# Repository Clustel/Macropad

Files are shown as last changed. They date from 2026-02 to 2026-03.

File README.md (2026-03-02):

# Squish Pad
A fully 3D-printable, true gasket-mounted 4x4 macropad engineered for a premium, ultra-smooth typing experience.

# Features
	16-Key Matrix + Rotary Encoder
	Engineered Leaf-Spring Plate providing a bouncy, trampoline-like typing fee
	Utilizes 3D-printed "slip-on" gasket socks to sandwich the plate tabs, completely isolating the plate and PCB from the outer case.
	Acoustic PCB Cushion

# Rendering


# Schematic
hackpad schematic

# PCB
hackpad pcb

# BOM
	1x unsoldered Seeed XIAO RP2040
	16x through-hole 1N4148 Diodes
	15x MX-Style switches
	1x EC11 Rotary encoders
	15x white blank DSA keycaps
	16x SK6812 MINI-E LEDs
	4x M3x16mm screws
	4x M3x5mx4mm heatset inserts
	1x Printed PCB
	1x Case (All parts, guide below)

# Printing Guide

> **If you dont have TPU:** Print the gaskets with PLA/PETG and don't print the cushion. The macropad will still be slightly flexible

| Part | Material | Key Settings |
| :--- | :--- | :--- |
| **Top & Bottom Case** | PLA-CF / PLA | Wall Loops: **5** \| Infill: **25% Gyroid** \| Layer: **0.16mm** |
| **Leaf-Spring Plate** | PETG | Wall Loops: **4** \| Layer: **0.15mm** \| Top/Bottom Layers: **5** |
| **Gaskets (x4)** | 95A TPU | Walls: **2** \| Top/Bottom: **0** \| Infill: **12% Gyroid** \| Speed: **3.5mm³/s** |
| **Cushion** | 95A TPU | Walls: **1** \| Top/Bottom: **0** \| Infill: **6% Gyroid** \| Speed: **3.5mm³/s** |

> **Note:** For the TPU parts, setting Top and Bottom layers to **0** is critical, this exposes the Gyroid infill to create the "squish" effect.

# Assembly guide
_Ensure all 3D-printed parts are cleaned of support material before starting._

> Bottom Case
> 
> 

> Add Cushion (if using TPU)
> 
> 

> Assemble PCB (might be easier to add keycaps in the next step)
> 
> 

> Add Plate
> 
> 

> Put assembly on top of cushion
>
> 

> Put Gaskets on all four sides of plate
> 
> 

> Add top (put heat inserts in the 4 holes)
> 
> 

> Use the screws to attach it together
> 
> 

> Done!
> 
>

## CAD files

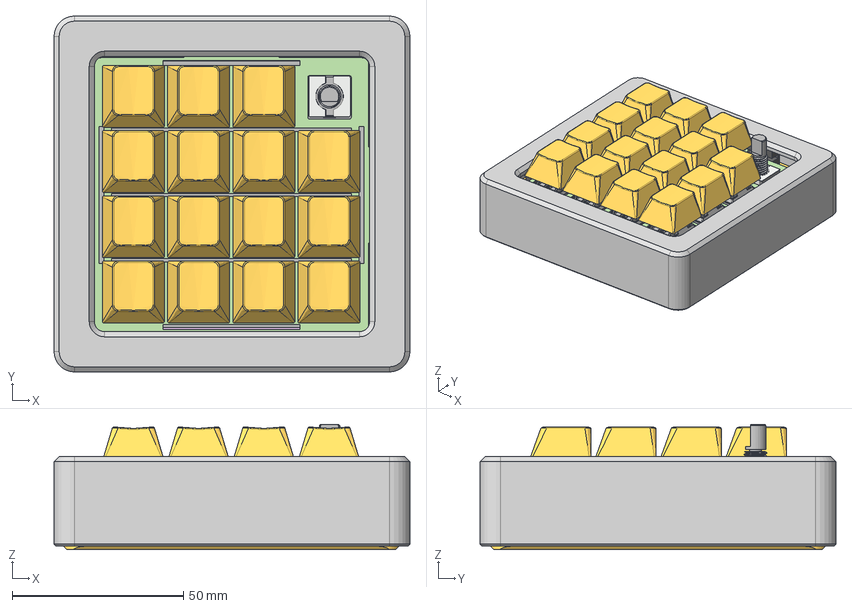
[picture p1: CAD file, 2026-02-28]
CAD/CAD Assembly.step
104.0 x 104.0 x 36.6 mm
Base
Socket button head screw M3x0.5 x 16 x 4
Gasket x 4
Top
r1_100 x 15
��ת������ x 6
Smaller pad
MX ? ??��_�?�__ x 15
MX? ?? ?? ?�2__??_�2____�_ x 15
MX ? ???_�___�1 x 15
??___??__�_ x 30
Seeed Studio XIAO RP2040 v26 x 36
type-c v2 x 24
main x 16
smd_button v3(Mirror)
VSS
VDD
DIN
DOUT
smd_button v3

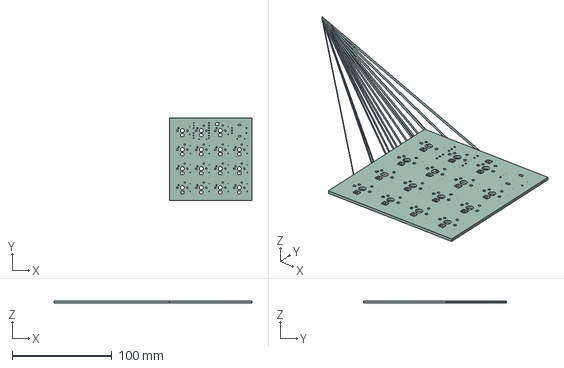
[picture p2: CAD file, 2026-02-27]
PCB/Custom Macropad.step
198.4 x 142.9 x 1.51 mm

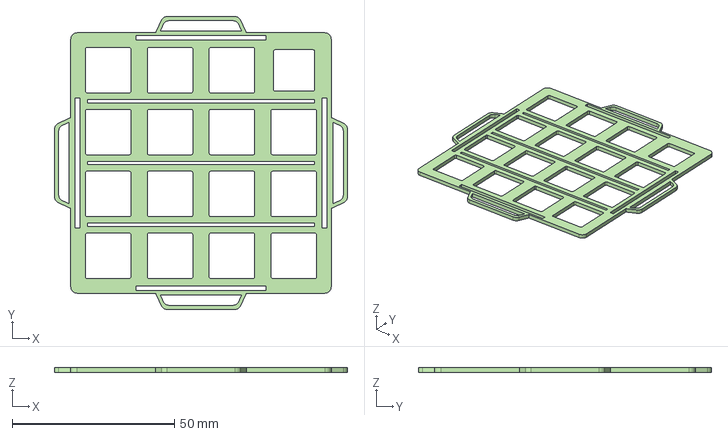
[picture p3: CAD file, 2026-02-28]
Production/Plate.step
90.2 x 90.2 x 1.51 mm

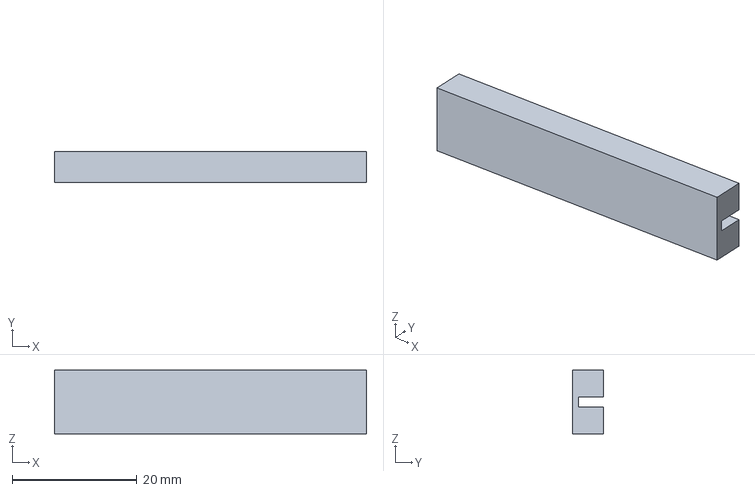
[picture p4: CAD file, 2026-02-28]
Production/Gasket x4.step
50.0 x 5.00 x 10.2 mm

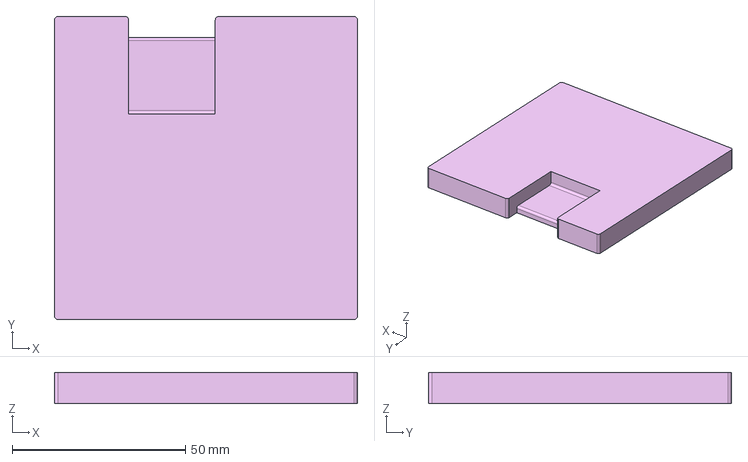
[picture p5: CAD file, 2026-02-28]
Production/Cushion.step
87.5 x 87.5 x 9.00 mm

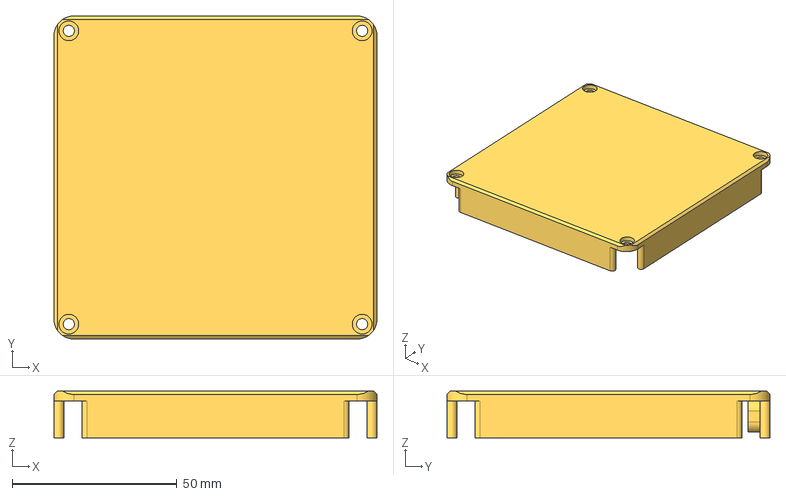
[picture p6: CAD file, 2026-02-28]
Production/Bottom.step
98.0 x 98.0 x 14.2 mm

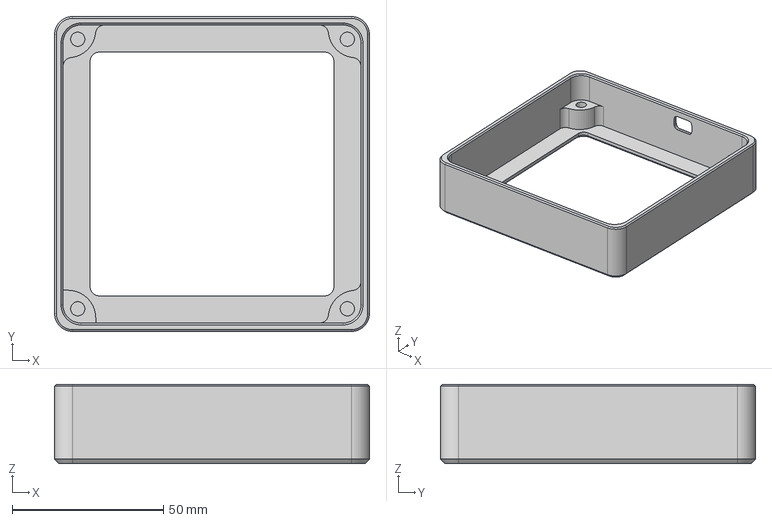
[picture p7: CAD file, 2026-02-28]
Production/Top.step
104.0 x 104.0 x 26.2 mm

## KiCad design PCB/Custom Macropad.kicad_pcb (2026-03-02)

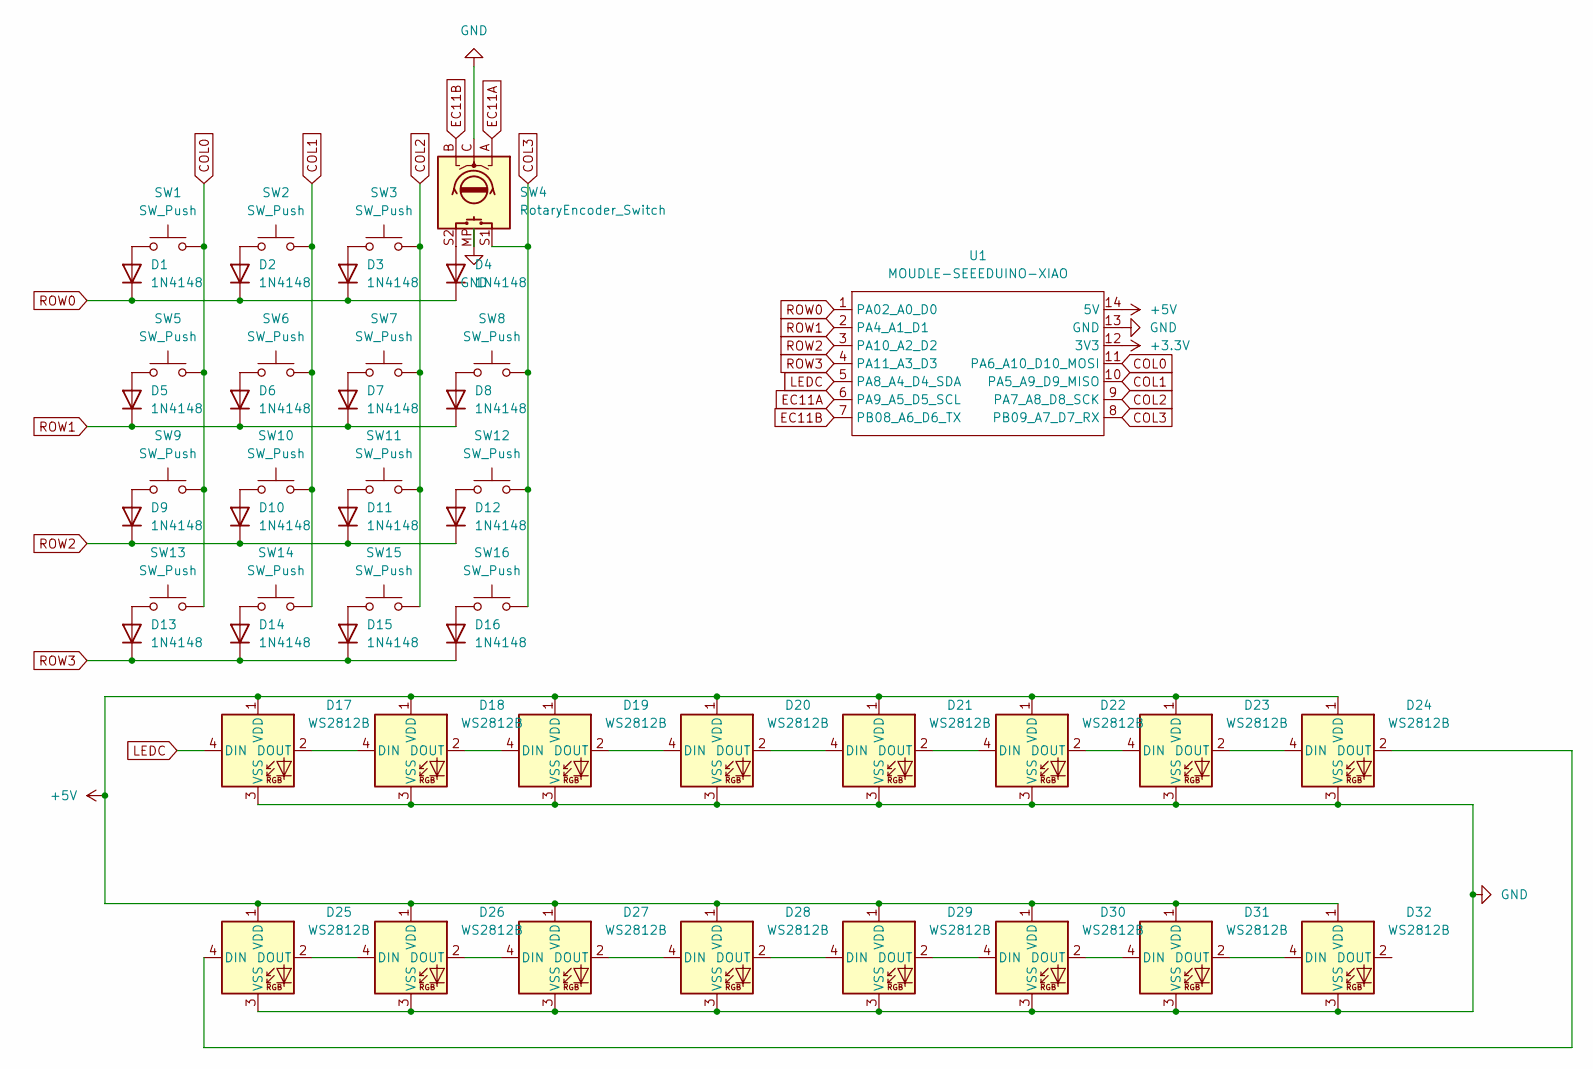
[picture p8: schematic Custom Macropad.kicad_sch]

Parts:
D1, D2, D3, D4, D5, D6, D7, D8, D9, D10, D11, D12, D13, D14, D15, D16: 1N4148; D_DO-35_SOD27_P7.62mm_Horizontal
D17, D18, D19, D20, D21, D22, D23, D24, D25, D26, D27, D28, D29, D30, D31, D32: WS2812B; SK6812MINI-E_fixed
SW1, SW2, SW3, SW5, SW6, SW7, SW8, SW9, SW10, SW11, SW12, SW13, SW14, SW15, SW16: SW_Push; SW_Cherry_MX_1.00u_PCB
SW4: RotaryEncoder_Switch; RotaryEncoder_Alps_EC11E-Switch_Vertical_H20mm
U1: MOUDLE-SEEEDUINO-XIAO; XIAO-Generic-Hybrid-14P-2.54-21X17.8MM

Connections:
+3.3V: U1.12 (3V3)
+5V: D17.1 (VDD), D18.1 (VDD), D19.1 (VDD), D20.1 (VDD), D21.1 (VDD), D22.1 (VDD), D23.1 (VDD), D24.1 (VDD), D25.1 (VDD), D26.1 (VDD), D27.1 (VDD), D28.1 (VDD), D29.1 (VDD), D30.1 (VDD), D31.1 (VDD), D32.1 (VDD), U1.14 (5V)
COL0: SW1.2, SW5.2, SW9.2, SW13.2, U1.11 (PA6_A10_D10_MOSI)
COL1: SW2.2, SW6.2, SW10.2, SW14.2, U1.10 (PA5_A9_D9_MISO)
COL2: SW3.2, SW7.2, SW11.2, SW15.2, U1.9 (PA7_A8_D8_SCK)
COL3: SW4.S1, SW8.2, SW12.2, SW16.2, U1.8 (PB09_A7_D7_RX)
EC11A: SW4.A, U1.6 (PA9_A5_D5_SCL)
EC11B: SW4.B, U1.7 (PB08_A6_D6_TX)
GND: D17.3 (VSS), D18.3 (VSS), D19.3 (VSS), D20.3 (VSS), D21.3 (VSS), D22.3 (VSS), D23.3 (VSS), D24.3 (VSS), D25.3 (VSS), D26.3 (VSS), D27.3 (VSS), D28.3 (VSS), D29.3 (VSS), D30.3 (VSS), D31.3 (VSS), D32.3 (VSS), SW4.C, SW4.MP (Shield), U1.13 (GND)
LEDC: D17.4 (DIN), U1.5 (PA8_A4_D4_SDA)
unnamed: D1.2 (A), SW1.1
unnamed: D2.2 (A), SW2.1
unnamed: D3.2 (A), SW3.1
unnamed: D4.2 (A), SW4.S2
unnamed: D5.2 (A), SW5.1
unnamed: D6.2 (A), SW6.1
unnamed: D7.2 (A), SW7.1
unnamed: D8.2 (A), SW8.1
unnamed: D9.2 (A), SW9.1
unnamed: D10.2 (A), SW10.1
unnamed: D11.2 (A), SW11.1
unnamed: D12.2 (A), SW12.1
unnamed: D13.2 (A), SW13.1
unnamed: D14.2 (A), SW14.1
unnamed: D15.2 (A), SW15.1
unnamed: D16.2 (A), SW16.1
unnamed: D17.2 (DOUT), D18.4 (DIN)
unnamed: D18.2 (DOUT), D19.4 (DIN)
unnamed: D19.2 (DOUT), D20.4 (DIN)
unnamed: D20.2 (DOUT), D21.4 (DIN)
unnamed: D21.2 (DOUT), D22.4 (DIN)
unnamed: D22.2 (DOUT), D23.4 (DIN)
unnamed: D23.2 (DOUT), D24.4 (DIN)
unnamed: D24.2 (DOUT), D25.4 (DIN)
unnamed: D25.2 (DOUT), D26.4 (DIN)
unnamed: D26.2 (DOUT), D27.4 (DIN)
unnamed: D27.2 (DOUT), D28.4 (DIN)
unnamed: D28.2 (DOUT), D29.4 (DIN)
unnamed: D29.2 (DOUT), D30.4 (DIN)
unnamed: D30.2 (DOUT), D31.4 (DIN)
unnamed: D31.2 (DOUT), D32.4 (DIN)
ROW0: D1.1 (K), D2.1 (K), D3.1 (K), D4.1 (K), U1.1 (PA02_A0_D0)
ROW1: D5.1 (K), D6.1 (K), D7.1 (K), D8.1 (K), U1.2 (PA4_A1_D1)
ROW2: D9.1 (K), D10.1 (K), D11.1 (K), D12.1 (K), U1.3 (PA10_A2_D2)
ROW3: D13.1 (K), D14.1 (K), D15.1 (K), D16.1 (K), U1.4 (PA11_A3_D3)

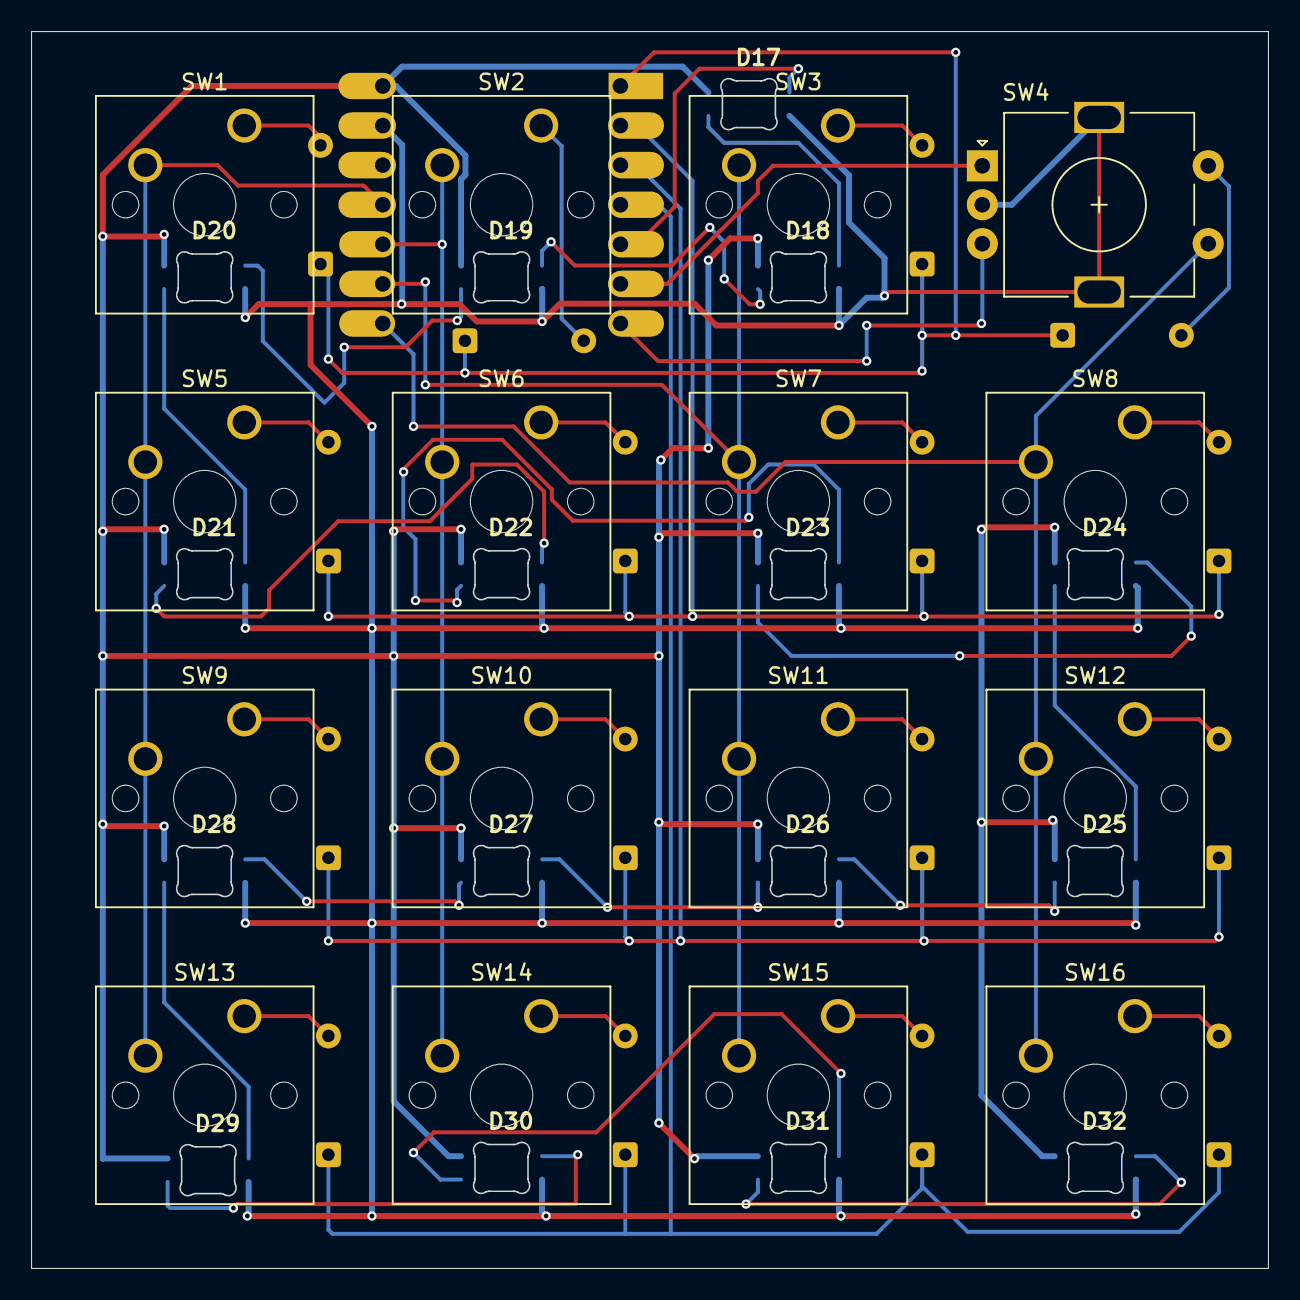
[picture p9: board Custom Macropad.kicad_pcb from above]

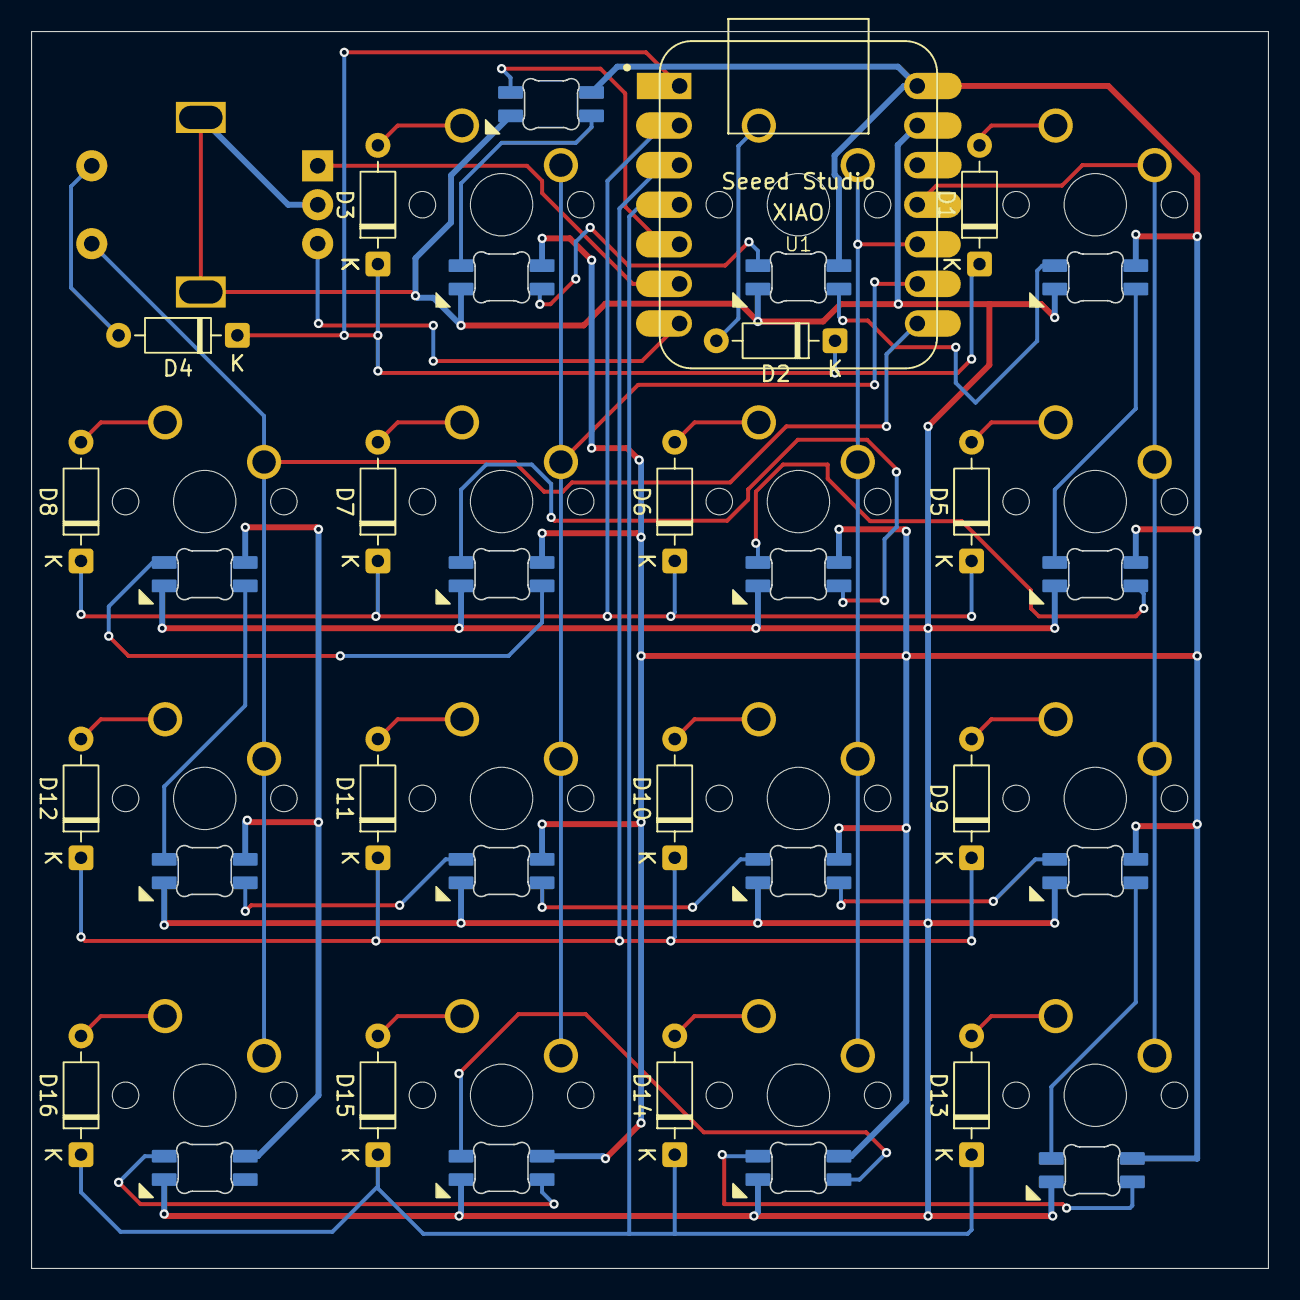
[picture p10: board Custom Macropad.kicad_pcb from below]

Board: 2 copper layers, 79.4 x 79.4 mm, 49 parts (17 on the bottom side), 44 nets.

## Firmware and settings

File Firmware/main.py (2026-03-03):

import board
from kmk.kmk_keyboard import KMKKeyboard
from kmk.keys import KC
from kmk.scanners import DiodeOrientation
from kmk.modules.encoder import EncoderHandler
from kmk.extensions.rgb import RGB

keyboard = KMKKeyboard()

keyboard.col_pins = (board.D10, board.D9, board.D8, board.D7)
keyboard.row_pins = (board.D0, board.D1, board.D2, board.D3)
keyboard.diode_orientation = DiodeOrientation.COL2ROW 

encoder_handler = EncoderHandler()
encoder_handler.pins = ((board.D5, board.D6, None, False),) 
keyboard.modules.append(encoder_handler)

rgb = RGB(
    pixel_pin=board.D4, 
    num_pixels=16,       
    val_limit=150,      
    hue_default=160,     
    sat_default=255,
    val_default=100,
)
keyboard.extensions.append(rgb)

keyboard.keymap = [
    [
        KC.N7, KC.N8, KC.N9, KC.MUTE, 
        KC.N4, KC.N5, KC.N6, KC.A,    
        KC.N1, KC.N2, KC.N3, KC.B,  
        KC.N0, KC.DOT, KC.ENT, KC.C  
    ]
]


encoder_handler.map = [
    ((KC.VOLD, KC.VOLU),) 
]

if __name__ == '__main__':
    keyboard.go()

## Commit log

2026-02-12 First Schematic Iteration
    [Custom Macropad.kicad_pcb, Custom Macropad.kicad_sch]
2026-02-13 Schematic V1
    [Custom Macropad.kicad_sch]
2026-02-19 Key pcb layout
    [Custom Macropad.kicad_pcb, Custom Macropad.kicad_sch]
2026-02-19 full pcb layout done w/o routing
    [Custom Macropad.kicad_pcb, Custom Macropad.kicad_sch]
2026-02-19 Finished routing v1
    [Custom Macropad.kicad_pcb, Custom Macropad.kicad_sch]
2026-02-28 Final v2
    [Custom Macropad.kicad_pcb]
2026-02-28 needed files
    [Bottom.step, CAD Assembly.step, CAD.step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]
2026-03-02 renamed to PCB
    [Custom Macropad.kicad_pcb, Custom Macropad.kicad_sch, Custom Macropad.step]
2026-03-02 Add PCB and case to parts list in README
2026-03-02 Added assembly guide
    Updated assembly guide with new image sizes and instructions.
